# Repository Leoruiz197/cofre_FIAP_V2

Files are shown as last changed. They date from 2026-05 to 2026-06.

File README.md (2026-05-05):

# 🔐 Cofre Inteligente FIAP V2

Projeto desenvolvido para a FIAP com o objetivo de criar um **cofre interativo e conectado**, utilizando ESP32, sensores e atuadores, com controle remoto via WebSocket.

---

## 🚀 Visão Geral

O sistema simula um cofre inteligente com:

- 🔐 Trava controlada por servo motor
- 💡 Iluminação com LEDs endereçáveis (NeoPixel)
- 🔊 Reprodução de áudio com DFPlayer Mini
- 🌫️ Máquina de fumaça
- 📡 Comunicação em tempo real via WebSocket
- 📶 Configuração dinâmica de rede (WiFiManager)
- 📊 Detecção de impacto com MPU6050

---

## 🧠 Funcionalidades

- Controle remoto via backend
- Execução de comandos em lote (batch)
- Configuração persistente (memória interna)
- Feedback visual e sonoro
- Detecção de impacto com resposta automática

---

## 🧩 Arquitetura do Projeto
src/
├── main.cpp
├── config.h
├── hardware.cpp
├── hardware.h
├── dfplayer.cpp
├── dfplayer.h
├── system_state.cpp
├── system_state.h
├── websocket.cpp
├── websocket.h
│
├── tasks/
│   ├── mpu_task.cpp
│   ├── mpu_task.h
│   ├── status_task.cpp
│   ├── status_task.h
│   ├── websocket_task.cpp
│   ├── websocket_task.h
│   ├── wifi_task.cpp
│   ├── wifi_task.h

---

## ⚙️ Hardware Utilizado

- ESP32
- MPU6050 (acelerômetro)
- DFPlayer Mini
- Servo Motor (trava)
- LEDs NeoPixel (2 fitas)
- Módulo de fumaça
- Fonte externa adequada

---

## 📡 Comunicação (WebSocket)

O dispositivo se conecta a um servidor WebSocket e recebe comandos no formato JSON.

### Exemplo de comando:

```json
{
  "type": "batch",
  "commands": [
    {
      "command": "LOCK",
      "action": "OPEN"
    },
    {
      "command": "LED",
      "target": "ALL",
      "effect": "SOLID",
      "r": 255,
      "g": 0,
      "b": 0
    }
  ]
}

🛠️ Como rodar o projeto (PlatformIO + VS Code)
📌 1. Instalar o VS Code

Baixe e instale:

👉 https://code.visualstudio.com/

📌 2. Instalar o PlatformIO
Abra o VS Code
Vá em Extensions (Ctrl + Shift + X)
Busque por:
PlatformIO IDE
Clique em Install

⏳ Aguarde a instalação completa (pode demorar alguns minutos)

📌 3. Clonar o repositório

No terminal do VS Code:

git clone https://github.com/Leoruiz197/cofre_FIAP_V2.git

Ou baixe o ZIP e extraia.

📌 4. Abrir o projeto

No VS Code:

File → Open Folder

Selecione a pasta do projeto.

📌 5. Conectar o ESP32
Conecte o ESP32 via USB
Verifique a porta COM

📌 6. Compilar o projeto

Clique no botão:

✔️ Build

ou use:

pio run

📌 7. Enviar o firmware

Clique em:

➡️ Upload

ou:

pio run --target upload

📌 8. Monitor serial

Para ver logs:

pio device monitor

ou botão:

🔌 Monitor

# 📶 Configuração Wi-Fi

Na primeira execução (ou após reset):

O ESP cria uma rede:
Cofre-Setup
Conecte pelo celular ou PC
Acesse:
192.168.4.1
Configure:
Wi-Fi
Servidor WebSocket
Porta
Device ID

🔄 Reset de configuração

Para resetar o Wi-Fi:

👉 Segure o botão BOOT ao ligar o ESP32

🎵 Áudio (DFPlayer)

Os arquivos devem estar no cartão SD:

0001.mp3
0002.mp3
0003.mp3
0004.mp3

Formato recomendado:

MP3
128kbps

⚠️ Observações importantes
O sistema utiliza tarefas (FreeRTOS)
Evitar uso de delay() em partes críticas
Alimentação deve ser adequada (principalmente servo e LEDs)

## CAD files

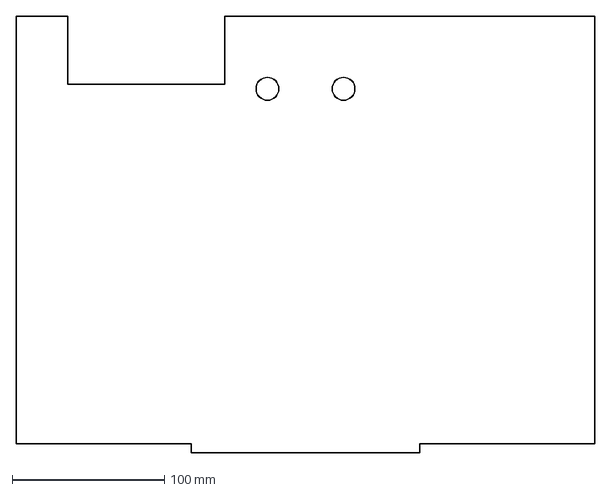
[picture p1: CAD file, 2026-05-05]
STLs/2d/gui1.dxf
380.0 x 286.7 mm

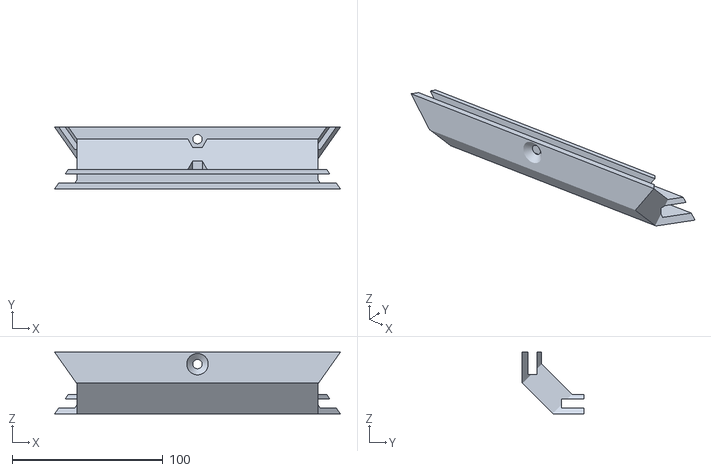
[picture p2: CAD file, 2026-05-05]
STLs/5.stl
189.4 x 41.0 x 41.0

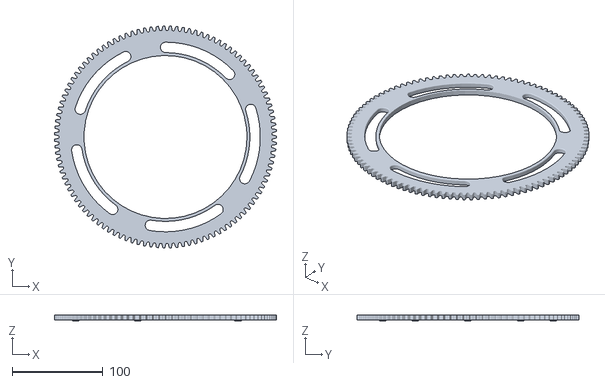
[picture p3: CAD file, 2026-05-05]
STLs/iris/coroa.stl
245.2 x 245.2 x 6.84

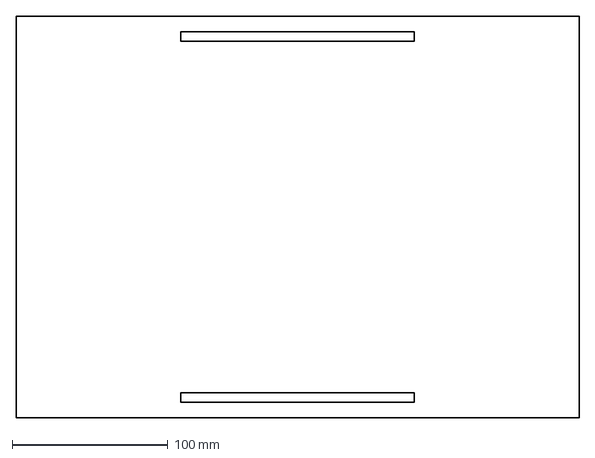
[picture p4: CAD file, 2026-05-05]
STLs/2d/gui3.dxf
362.0 x 258.0 mm

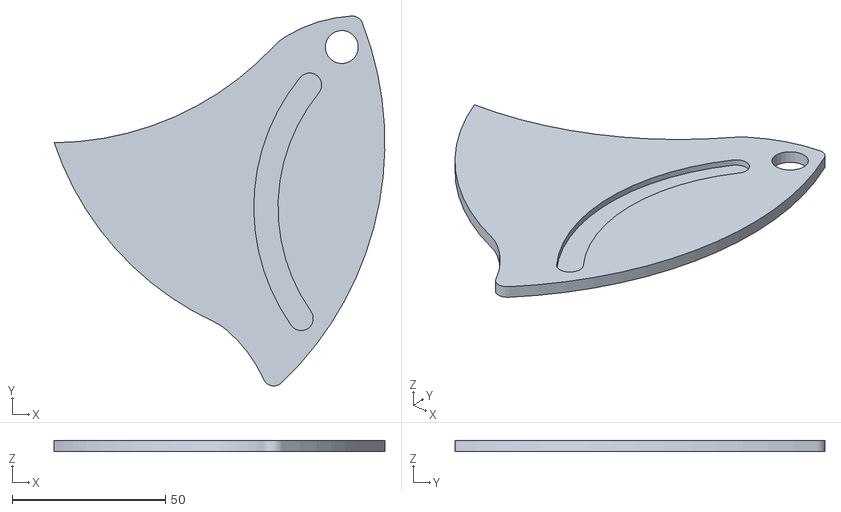
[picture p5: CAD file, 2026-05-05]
STLs/iris/door_blade_final.stl.stl
108.0 x 120.9 x 3.60

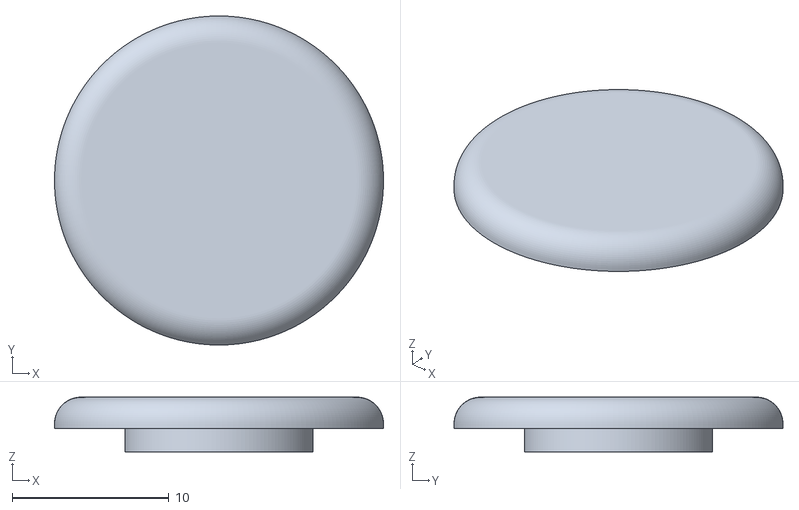
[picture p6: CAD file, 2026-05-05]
STLs/t1.stl
21.0 x 21.0 x 3.50

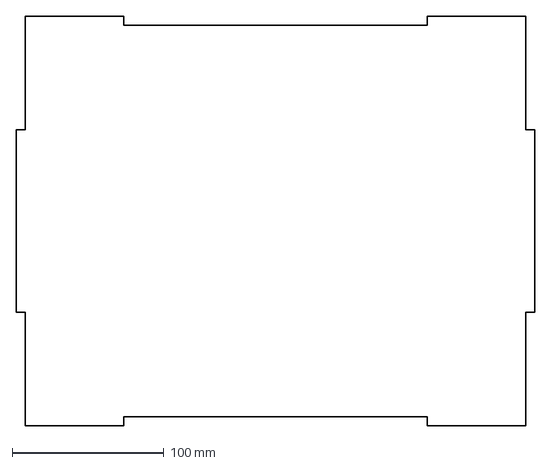
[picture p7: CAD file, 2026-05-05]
STLs/2d/5.dxf
342.0 x 270.0 mm

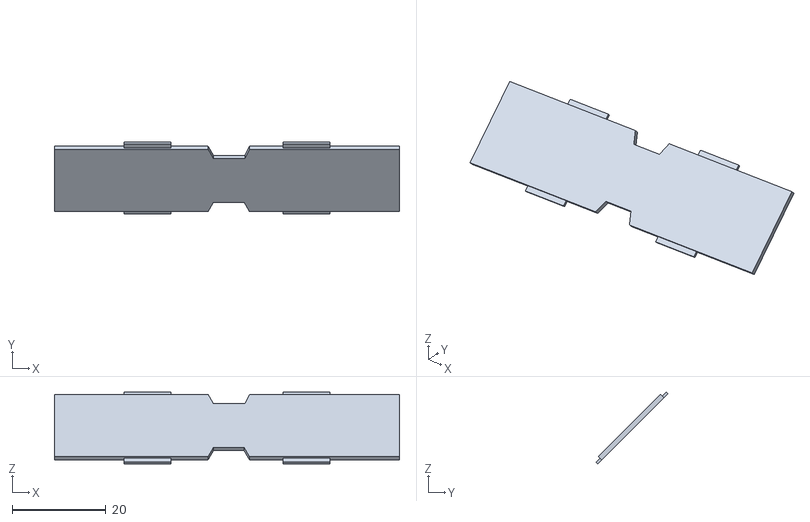
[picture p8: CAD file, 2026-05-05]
STLs/fiap2.stl
73.6 x 15.3 x 15.3

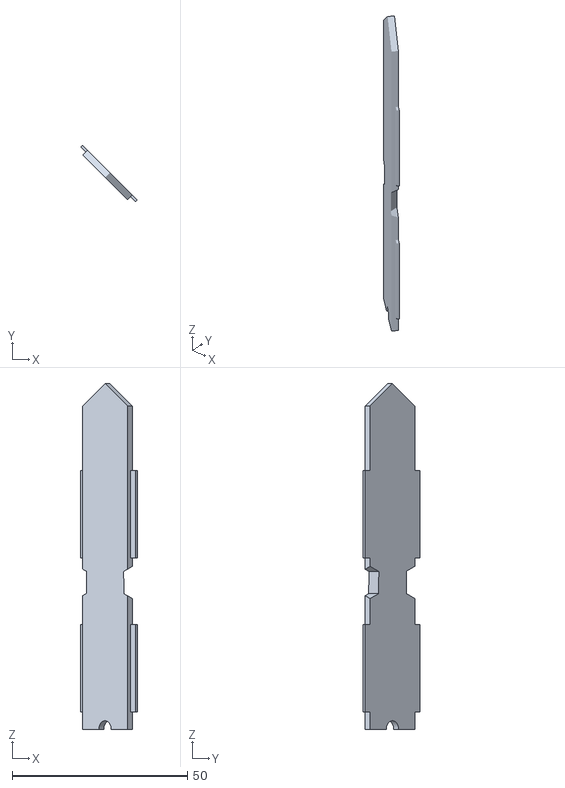
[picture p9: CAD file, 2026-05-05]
STLs/iris/led2.stl
16.2 x 16.2 x 98.7

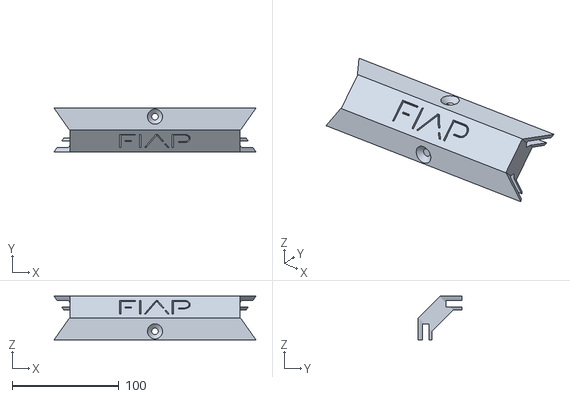
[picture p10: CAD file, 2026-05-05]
STLs/2.stl
189.4 x 41.0 x 41.0

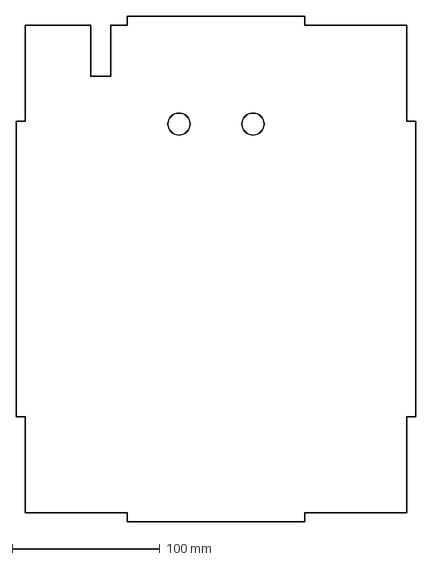
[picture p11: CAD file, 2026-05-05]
STLs/2d/6.dxf
270.0 x 342.0 mm

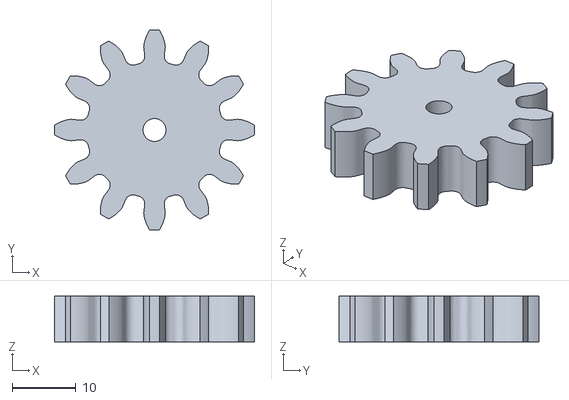
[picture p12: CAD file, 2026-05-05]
STLs/iris/spur-gear-12th-125mo-145at.stl.stl
31.5 x 31.5 x 7.20

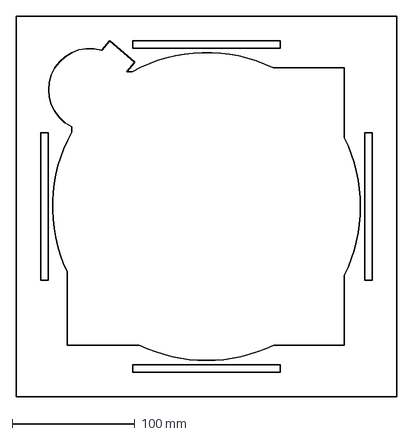
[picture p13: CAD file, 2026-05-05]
STLs/2d/7.dxf
310.0 x 310.0 mm

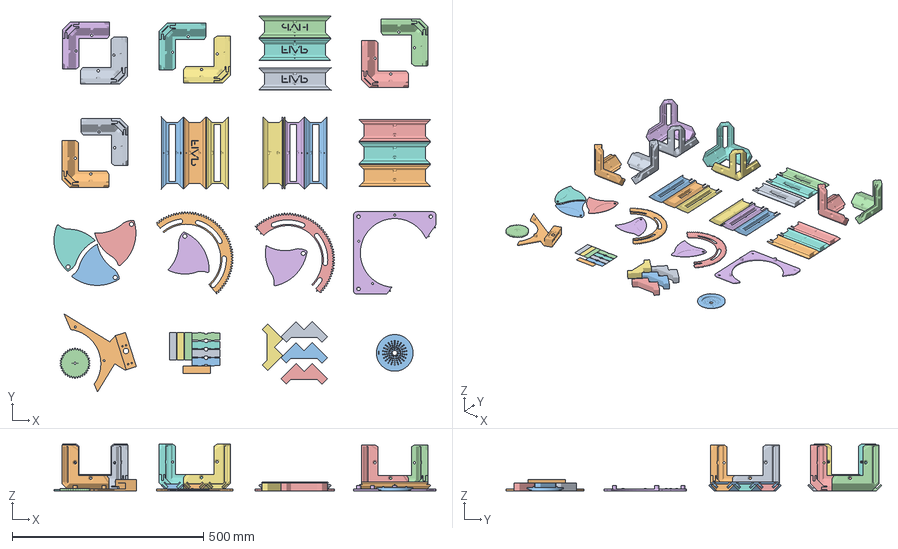
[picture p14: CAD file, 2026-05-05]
STLs/Impre.3mf
1000.0 x 984.0 x 123.0 mm
1.stl x 4
Corpo de malha1.stl x 2
3.stl x 4
Assembly
5.stl x 4
Corpo145.stl x 4
fiap2.stl x 4
coroa.stl x 2
fiap1.stl x 4
iris.stl x 5
2.stl x 4
4.stl x 4
altofalante.stl

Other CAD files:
STLs/iris/led3.stl
STLs/2d/4.dxf
STLs/fiap1.stl
STLs/iris/engrenagem pequena.stl
STLs/1.stl
STLs/2d/1.dxf
STLs/2d/2.dxf
STLs/2d/3.dxf
STLs/2d/8.dxf
STLs/2d/gui2.dxf
STLs/3.stl
STLs/4.stl
STLs/Corpo de malha1.stl
STLs/Corpo145.stl
STLs/altofalante.stl
STLs/apoio.stl
STLs/engrenagem grande.stl
STLs/iris/Petg1.stl
STLs/iris/Petg3.stl
STLs/iris/Pinhao.stl
STLs/iris/base iris.stl
STLs/iris/baseplate-aperature.stl.stl
STLs/iris/iris.stl
STLs/iris/led1.stl
STLs/iris/petg2.stl
STLs/iris/spur-gear-107th-125mo-145at.stl.stl
STLs/t2.stl

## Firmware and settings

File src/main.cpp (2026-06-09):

#include <Arduino.h>
#include "hardware.h"
#include "tasks/wifi_task.h"
#include "tasks/websocket_task.h"
#include "tasks/status_task.h"
#include "tasks/mpu_task.h"

TaskHandle_t mpuTaskHandle = NULL;

void setup() {
    Serial.begin(115200);
    randomSeed(esp_random());
    loadServoAngles();
    hardwareInit();
    setDoorClose();
    setLED2(220, 0, 70);

    // Serial.println("TESTE SERVO DIRETO");

    // setServo(20);
    // delay(2000);

    // setServo(90);
    // delay(2000);

    // setServo(150);
    // delay(2000);

    // WIFI
    xTaskCreatePinnedToCore(
        wifiTask,
        "WiFi Task",
        10000,
        NULL,
        1,
        NULL,
        0
    );

    // WEBSOCKET
    xTaskCreatePinnedToCore(
        websocketTask,
        "WebSocket Task",
        10000,
        NULL,
        1,
        NULL,
        1
    );

    // STATUS
    xTaskCreatePinnedToCore(
        statusTask,
        "Status Task",
        15000,
        NULL,
        1,
        NULL,
        1
    );
    // MPU
    xTaskCreatePinnedToCore(
        mpuTask,
        "MPU Task",
        4096,
        NULL,
        1,
        &mpuTaskHandle,
        1
    );
}

void loop() {
    // vazio
}

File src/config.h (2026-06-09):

#pragma once

#define SERVO_PIN 33
#define LED1_PIN 18
#define LED2_PIN 19
#define SMOKE_PIN 4
#define RESET_BUTTON_PIN 0

#define DF_RX 17
#define DF_TX 16

#define MPU_ADDR 0x68

#define LED1_COUNT 24
#define LED2_COUNT 24
#define LED_INT_COUNT 8

#define STATUS_INTERVAL 5000

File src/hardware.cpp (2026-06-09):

#include "config.h"
#include <Adafruit_NeoPixel.h>
#include <ESP32Servo.h>
#include "system_state.h"
#include "hardware.h"
#include "dfplayer.h"
#include <Preferences.h>

Preferences hardwarepreferences;

Servo servo;

Adafruit_NeoPixel led1(LED1_COUNT, LED1_PIN, NEO_GRB + NEO_KHZ800);
Adafruit_NeoPixel led2(LED2_COUNT, LED2_PIN, NEO_GRB + NEO_KHZ800);

void loadServoAngles() {
    hardwarepreferences.begin("cofre", true);

    doorOpenAngle = hardwarepreferences.getInt("openAngle", 30);
    doorCloseAngle = hardwarepreferences.getInt("closeAngle", 160);

    hardwarepreferences.end();

    Serial.println("[EEPROM] Angulos carregados:");
    Serial.print("Open: ");
    Serial.println(doorOpenAngle);
    Serial.print("Close: ");
    Serial.println(doorCloseAngle);
}

void saveServoAngles(int openAngle, int closeAngle) {
    doorOpenAngle = constrain(openAngle, 0, 180);
    doorCloseAngle = constrain(closeAngle, 0, 180);

    hardwarepreferences.begin("cofre", false);

    hardwarepreferences.putInt("openAngle", doorOpenAngle);
    hardwarepreferences.putInt("closeAngle", doorCloseAngle);

    hardwarepreferences.end();

    Serial.println("[EEPROM] Angulos salvos:");
    Serial.print("Open: ");
    Serial.println(doorOpenAngle);
    Serial.print("Close: ");
    Serial.println(doorCloseAngle);
}

void hardwareInit() {
    pinMode(SMOKE_PIN, OUTPUT);
    setSmoke(true);
    delay(1000);
    setSmoke(false);

    Serial.println("[HW] Inicializando servo...");
    servo.setPeriodHertz(50);
    servo.attach(SERVO_PIN, 500, 2500);

    led1.begin();
    led1.clear();
    led1.show();
    
    led2.begin();
    led2.clear();
    led2.show();

    setLED2(220,0,70);
    initDFPlayer();
}

void setServo(int angle) {
    angle = constrain(angle, 0, 180);

    servo.write(angle);
    servoAngle = angle;

    Serial.print("[SERVO] Angulo direto: ");
    Serial.println(angle);
}

void setDoorOpen() {
    servo.write(doorOpenAngle);
    doorOpen = true;

    servoAngle = doorOpenAngle;

    Serial.print("[SERVO] Abrindo porta: ");
    Serial.println(doorOpenAngle);
}

void setDoorClose() {
    servo.write(doorCloseAngle);
    doorOpen = false;

    servoAngle = doorCloseAngle;

    Serial.print("[SERVO] Fechando porta: ");
    Serial.println(doorCloseAngle);
}

void setSmoke(bool state) {
    smokeActive = state;
    // LOW = ligado | HIGH = desligado
    digitalWrite(SMOKE_PIN, state ? LOW : HIGH);

    Serial.print("[SMOKE] Estado: ");
    Serial.println(state ? "ON" : "OFF");
}

void setLED1(int r, int g, int b) {
    strip1R = r;
    strip1G = g;
    strip1B = b;

    for(int i = 0; i < LED1_COUNT; i++) {
        led1.setPixelColor(i, led1.Color(r, g, b));
    }
    led1.show();

    Serial.println("[HW] LED1 atualizado");
}

void setLED2(int r, int g, int b) {
    strip2R = r;
    strip2G = g;
    strip2B = b;

    for(int i = 0; i < LED2_COUNT-8; i++) {
        led2.setPixelColor(i, led2.Color(r, g, b));
    }
    led2.show();

    Serial.println("[HW] LED2 atualizado");
}

void luzInterno(bool on) {
    internalLightOn = on;

    int start = LED2_COUNT - LED_INT_COUNT;

    for (int i = start; i < LED2_COUNT; i++) {
        led2.setPixelColor(
            i,
            on ? led2.Color(255, 255, 255) : led2.Color(0, 0, 0)
        );
    }

    led2.show();

    Serial.println("[HW] LED Interno atualizado");
}

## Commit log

2026-05-02 ajuste de wifimanager servo e leds
2026-05-03 deteccao de impacto funcionando
2026-05-03 alteracao de status so com mudanca, som e fumaca ok
2026-05-03 ajsute de led
2026-05-03 ajsute de status
2026-05-05 ajuste de sounds
2026-05-05 ajsute de luz interna
2026-05-05 ajuste de vencedor
2026-05-05 ajuste de porta
2026-05-05 ajuste de var
2026-05-05 ajuste de readme e sound
2026-05-05 partes STL
    [1.dxf, 1.stl, 2.dxf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]
2026-05-05 teste de servo inicial
2026-05-06 ajuste de ID do cofre manual
2026-05-07 ajuste de firmeware
2026-06-09 updates de bugs
2026-07-17 ajuste de tracks
2026-08-07 Ajuste de fila WS
2026-08-07 Ajuste de MPU
2026-08-07 Ajuste de Cofre Offline
